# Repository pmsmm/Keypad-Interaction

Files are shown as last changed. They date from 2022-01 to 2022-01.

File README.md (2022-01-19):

# Keypad Interaction

The Keypad Interaction is a mini game that was developed for my Master Thesis "Developing a Support Infrastructure for an Escape The Room and Peddy Paper Games".

This mini game, or interaction as I so call it, was developed to be part of an Escape the Room game that was also developed as part of my thesis. Since this interaction can work as a standalone mini game I decided to place it here for anyone interested in using it.

## List of Components

- Otemu Mechanical Switch (16x);
- Diode 1n4148 (16x);
- Display LCD 16x2 1602 I2C IIC (1x);
- Red LED (1x);
- Green LED (1x);
- 220Ω Resistor (2x);
- Arduino Nano (1x);

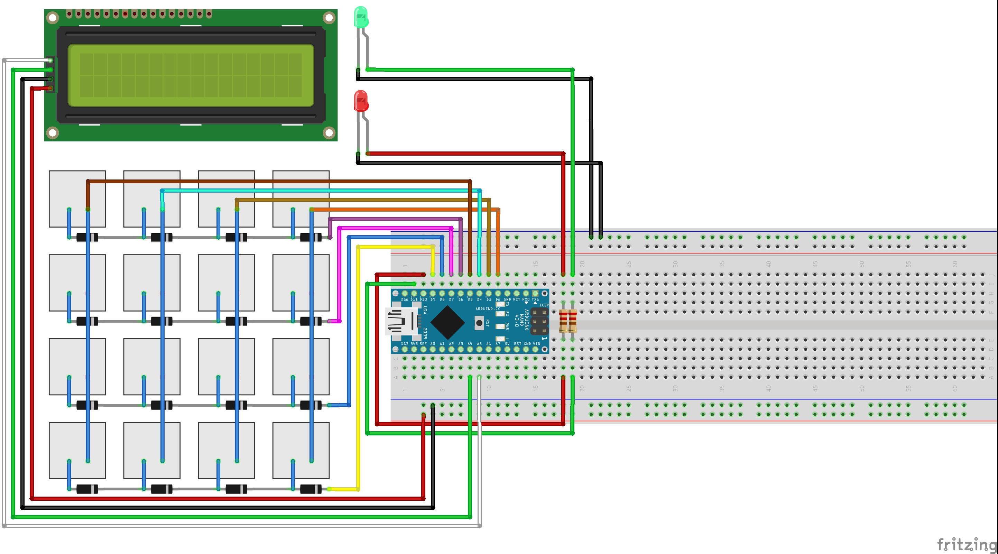
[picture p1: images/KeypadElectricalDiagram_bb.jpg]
Wiring Diagram


In order to fully assemble the Interaction, so as to look like the picture below, you will also need to 3D Print the enclosure which is divided into two parts that can be found [here](enclosure/). Additionally, you will also need to 3D Print the keycaps which **were not** designed by me but can be found in [Thingiverse](https://www.thingiverse.com/thing:2783650).

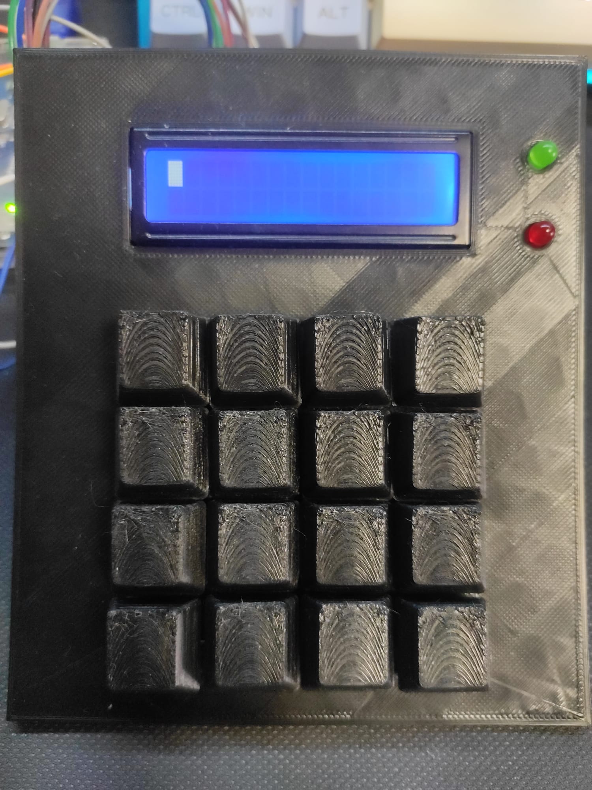
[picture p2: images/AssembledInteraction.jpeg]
Assembled Interaction


## The Purpose of The Game

This game was intended to be played as part of an Escape the Room but it can still be used as a fun project with other purposes besides a game. As many might have guessed, the purpose of this game is to introduce a secret code using the 4x4 keypad and if the code is correct the green LED will light up.

## Instructions

First start by uploading the code to your Arduino Nano (This is the one I used so I can only guarantee proper working with this micro-controller).

### Starting the Game

To start the game you must first type in the Arduino IDE serial monitor the following:

- `COM:START;ID:123456789`

This command will then print in the Serial Monitor the solution of the game which then needs to be introduced using the keypad. If the introduced code is correct then the following message will appear in the serial monitor:

- > COM:INTERACTION_SOLVED;MSG:User Guessed Code Correctly;PNT:2000

## Warning

The source code for this interaction contains a lot of logic that was made to communicate with the infrastructure that was developed for my thesis and therefor it is not as clean as it could be when compared to a mini game that is developed with the intent of being used by the Arduino IDE directly.

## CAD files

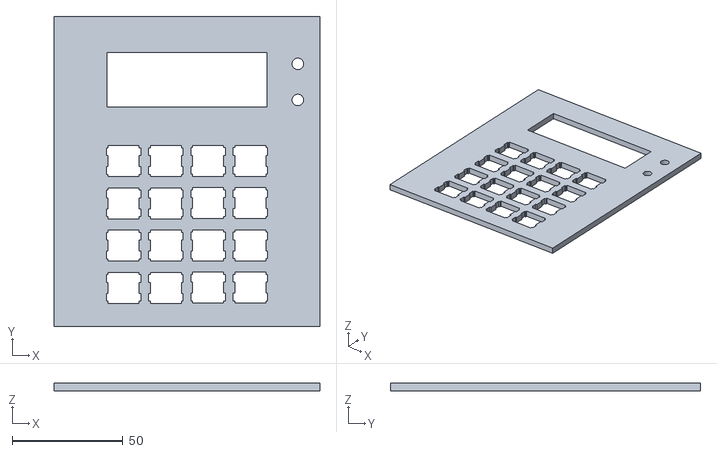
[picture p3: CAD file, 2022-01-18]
enclosure/Keypad Interaction - Plate.stl
120.0 x 140.0 x 3.50

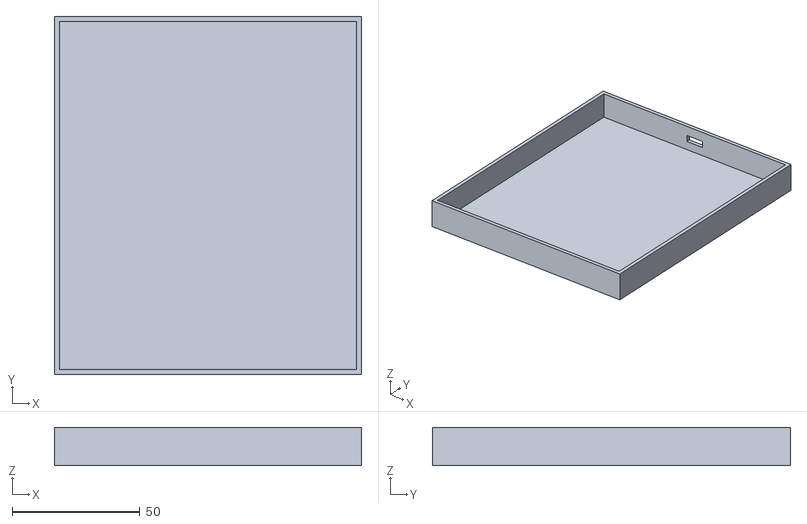
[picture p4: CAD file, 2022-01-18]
enclosure/Keypad Interaction - Case.stl
120.0 x 140.0 x 15.0

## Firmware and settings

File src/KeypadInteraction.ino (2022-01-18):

#include <LiquidCrystal_I2C.h>

const uint8_t redLED = 10;
const uint8_t greenLED = 11;

byte rows[] = {6, 7, 8, 9};
const int rowCount = sizeof(rows) / sizeof(rows[0]);

byte cols[] = {2, 3, 4, 5};
const int colCount = sizeof(cols) / sizeof(cols[0]);

byte keys[colCount][rowCount];
char numbers[colCount][rowCount] = {
  {'1', '2', '3', 'A'},
  {'4', '5', '6', 'B'},
  {'7', '8', '9', 'C'},
  {'*', 'D', '#', 'D'}
};

LiquidCrystal_I2C lcd(0x27, 16, 2);

char newSecretCode[8];
char introducedSecretCode[8];

int secretCodeIndex = 0;

bool INTERACTION_SOLVED, INTERACTION_RUNNING;

void setup() {
  Serial.begin(9600);
  randomSeed(analogRead(0));
  lcd.init();
  lcd.backlight();
  lcd.setCursor(0, 0);
  lcd.blink();
  pinMode(greenLED, OUTPUT);
  pinMode(redLED, OUTPUT);
}

void loop() {
  if (!Serial) {
    Serial.begin(9600);
  }
  if (Serial.available()) {
    processSerialMessage();
  }
  if (INTERACTION_SOLVED == false && INTERACTION_RUNNING == true) {
    gameLoop();
  }
}

void gameLoop() {
  char pressedKey = readMatrixAndReturnPressedKey();
  if (pressedKey != '\n') {
    if (secretCodeIndex < 8) {
      lcd.setCursor((4 + secretCodeIndex), 1);
      lcd.print(pressedKey);
      introducedSecretCode[secretCodeIndex] = pressedKey;
      secretCodeIndex += 1;
      if (secretCodeIndex == 8 and checkWinning()) {
        Serial.println("COM:INTERACTION_SOLVED;MSG:User Guessed Code Correctly;PNT:2000");
        Serial.flush();
      }
    } else {
      secretCodeIndex = 0;
    }
  }
  delay(225);
}

char readMatrixAndReturnPressedKey() {
  char pressedKey = '\n';
  while (pressedKey == '\n') {
    // iterate the columns
    for (int colIndex = 0; colIndex < colCount; colIndex++) {
      // col: set to output to low
      byte curCol = cols[colIndex];
      pinMode(curCol, OUTPUT);
      digitalWrite(curCol, LOW);

      // row: interate through the rows
      for (int rowIndex = 0; rowIndex < rowCount; rowIndex++) {
        byte rowCol = rows[rowIndex];
        pinMode(rowCol, INPUT_PULLUP);
        keys[colIndex][rowIndex] = digitalRead(rowCol);
        pinMode(rowCol, INPUT);
      }
      // disable the column
      pinMode(curCol, INPUT);
    }

    for (int colIndex = 0; colIndex < colCount; colIndex++) {
      for (int rowIndex = 0; rowIndex < rowCount; rowIndex++) {
        if (keys[colIndex][rowIndex] == LOW) {
          pressedKey = numbers[colIndex][rowIndex];
        }
      }
    }

    if (Serial.available()) {
      processSerialMessage();
      return '\n';
    }

  }

  return pressedKey;

}

void processSerialMessage() {
  const int BUFF_SIZE = 64; // make it big enough to hold your longest command
  static char buffer[BUFF_SIZE + 1]; // +1 allows space for the null terminator
  static int length = 0; // number of characters currently in the buffer

  char c = Serial.read();
  if ((c == '\r') || (c == '\n')) {
    // end-of-line received
    if (length > 0) {
      tokenizeReceivedMessage(buffer);
    }
    length = 0;
  } else {
    if (length < BUFF_SIZE) {
      buffer[length++] = c; // append the received character to the array
      buffer[length] = 0; // append the null terminator
    }
  }
}

void tokenizeReceivedMessage(char *msg) {
  const int COMMAND_PAIRS = 10;
  char* tokenizedString[COMMAND_PAIRS + 1];
  int index = 0;

  char* command = strtok(msg, ";");
  while (command != 0) {
    char* separator = strchr(command, ':');
    if (separator != 0) {
      *separator = 0;
      tokenizedString[index++] = command;
      ++separator;
      tokenizedString[index++] = separator;
    }
    command = strtok(0, ";");
  }
  tokenizedString[index] = 0;

  processReceivedMessage(tokenizedString);
}

void processReceivedMessage(char** command) {
  if (strcmp(command[1], "START") == 0) {
    startSequence(command[3]);
  } else if (strcmp(command[1], "PAUSE") == 0) {
    pauseSequence(command[3]);
  } else if (strcmp(command[1], "STOP") == 0) {
    stopSequence(command[3]);
  } else if (strcmp(command[1], "INTERACTION_SOLVED_ACK") == 0) {
    setInteractionSolved();
  } else if (strcmp(command[1], "PING") == 0) {
    ping(command[3]);
  } else if (strcmp(command[1], "BAUD") == 0) {
    setBaudRate(atoi(command[3]), command[5]);
  } else if (strcmp(command[1], "SETUP") == 0) {
    Serial.println("COM:SETUP;INT_NAME:Keypad Interaction;BAUD:9600");
    Serial.flush();
  }
}

void startSequence(char* TIMESTAMP) {
  for (int i = 0; i < 8; i++) {
    newSecretCode[i] = numbers[random(0, rowCount)][random(0, colCount)];
  }
  INTERACTION_SOLVED = false;
  INTERACTION_RUNNING = true;
  secretCodeIndex = 0;
  Serial.print("COM:START_ACK;MSG:");
  for (int i = 0; i < 8; i++) {
    Serial.print(newSecretCode[i]);
  }
  Serial.print(";ID:");
  Serial.print(TIMESTAMP);
  Serial.print("\r\n");
  Serial.flush();
  lcd.setCursor(0, 0);
  lcd.print("#Introduce Code#");
  lcd.setCursor(4, 1);
}

void pauseSequence(char* TIMESTAMP) {
  INTERACTION_RUNNING = !INTERACTION_RUNNING;
  if (INTERACTION_RUNNING) {
    Serial.print("COM:PAUSE_ACK;MSG:Device is now running;ID:");
  } else {
    Serial.print("COM:PAUSE_ACK;MSG:Device is now paused;ID:");
  }
  Serial.print(TIMESTAMP);
  Serial.print("\r\n");
  Serial.flush();
}

void stopSequence(char* TIMESTAMP) {
  INTERACTION_RUNNING = false;
  Serial.print("COM:STOP_ACK;MSG:Device is now stopped;ID:");
  Serial.print(TIMESTAMP);
  Serial.print("\r\n");
  Serial.flush();
}

void setInteractionSolved() {
  INTERACTION_SOLVED = true;
  INTERACTION_RUNNING = false;
}

void ping(char* TIMESTAMP) {
  Serial.print("COM:PING;MSG:PING;ID:");
  Serial.print(TIMESTAMP);
  Serial.print("\r\n");
  Serial.flush();
}

void setBaudRate(int baudRate, char* TIMESTAMP) {
  Serial.flush();
  Serial.begin(baudRate);
  Serial.print("COM:BAUD_ACK;MSG:The Baud Rate was set to ");
  Serial.print(baudRate);
  Serial.print(";ID:");
  Serial.print(TIMESTAMP);
  Serial.print("\r\n");
  Serial.flush();
}

bool checkWinning() {
  for (int i = 0; i < 8; i++) {
    if (introducedSecretCode[i] != newSecretCode[i]) {
      digitalWrite(redLED, HIGH);
      lcd.init();
      lcd.setCursor(0, 0);
      lcd.print("#Access Denied#");
      delay(1500);
      lcd.setCursor(0, 0);
      lcd.print("#Introduce Code#");
      lcd.setCursor(4, 1);
      lcd.backlight();
      digitalWrite(redLED, LOW);
      return false;
    }
  }
  digitalWrite(greenLED, HIGH);
  delay(1000);
  lcd.init();
  lcd.setCursor(0, 0);
  lcd.print("#Access Granted#");
  lcd.setCursor(4, 1);
  lcd.backlight();
  digitalWrite(greenLED, LOW);
  INTERACTION_SOLVED = true;
  return true;
}

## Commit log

2022-01-18 Initial Commit
    Added the source code;
    Uploaded the enclosure files;
    Uploaded the Wiring Diagram;
    Uploaded an image of the assembled interaction;
    [Keypad Interaction - Case.stl, Keypad Interaction - Plate.stl]
2022-01-18 Created the Readme.md file with all the relevant information
    [Keypad Interaction - Case.stl, Keypad Interaction - Plate.stl]
2022-01-18 Changed Readme to include image of assembled interaction
